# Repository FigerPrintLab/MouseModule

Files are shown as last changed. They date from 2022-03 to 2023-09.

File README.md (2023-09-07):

# MouseModule [WORK IN PROGRESS]

This is an eurorack module that processes mouse events through the [Raspberry Pi](https://www.raspberrypi.org/) and generates some analog signals. It offers also recording and playback capabilities with more complex mice.

## Build instructions 

This is a pretty simple module to build and try if you have a Raspberry Pi.

### Hardware

Inside the repository (in the KiCad folder) you'll find the schematic (the PCB is still WIP) that you can use to build a very simple prototype on a breadboard. All you need are some passive components, a general purpose opamp and a comparator (used as level translator from 3.3V to 5V).  
GPIO 4 can be tied to an LED to get visual feedback when you're recording. Same for GPIO 17 which signals that you're playing back the recorded events.

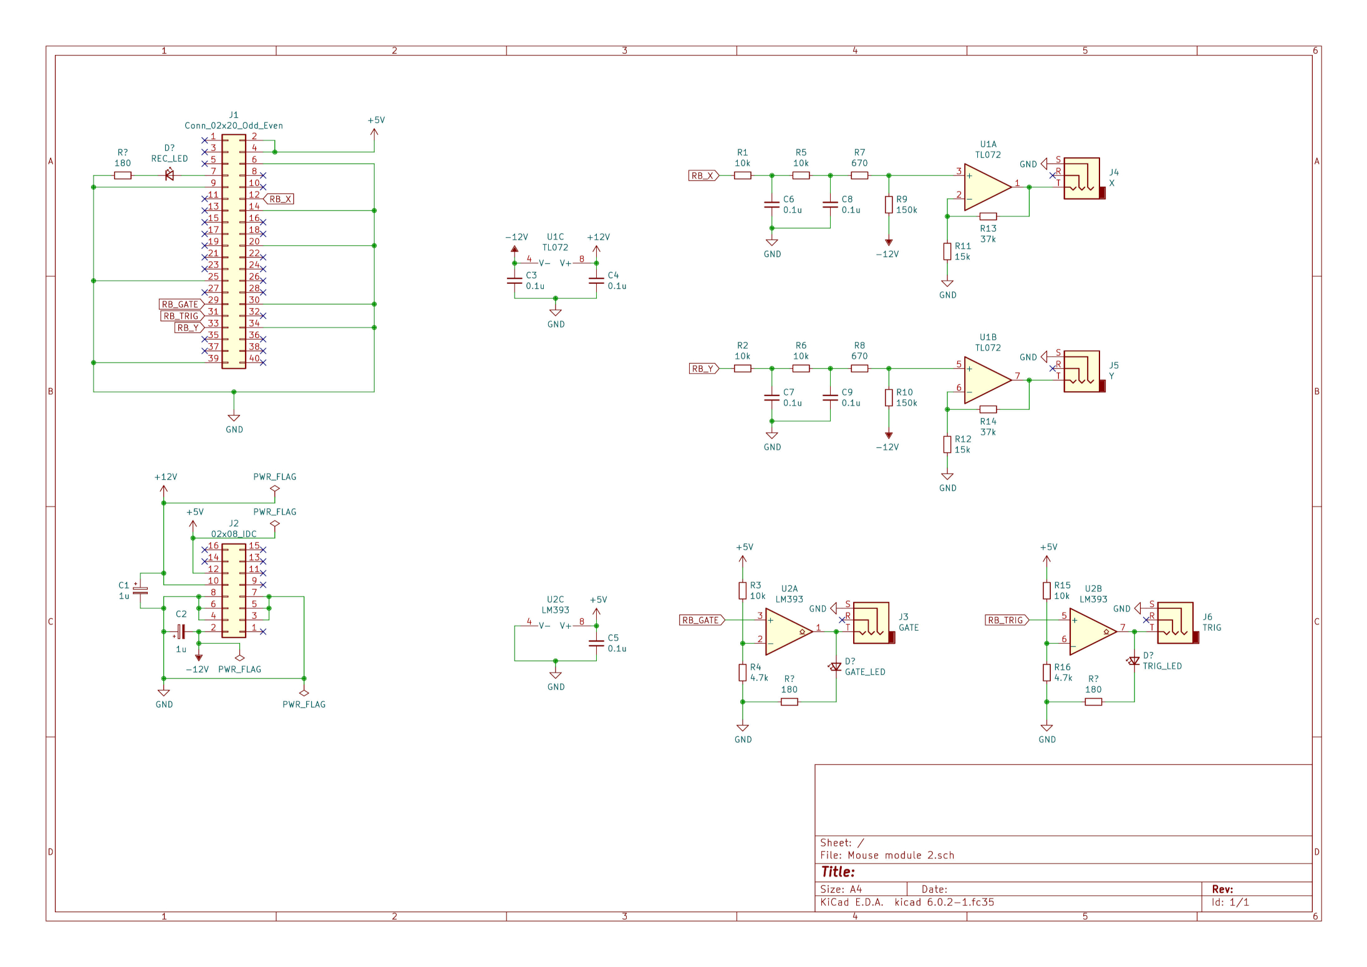
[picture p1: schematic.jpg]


### Software

The program is written in C and it captures all the relevant mouse events in order to generate the appropriate hardware signals on specific GPIOs (listed below). The software should be run on the minimal version of the Pi OS (Raspberry Pi OS Lite) because of the lack of a graphical server which could behave weirdly with the mouse events. In order to compile it you need to install the [`pigpio` library](https://abyz.me.uk/rpi/pigpio/) which requires privileged permissions to run.

```sh
# clone the repository
git clone https://github.com/FingerprintLab/MouseModule.git
cd MouseModule

# install the dependency
sudo apt update && sudo apt upgrade -y
sudo apt install -y pigpio

# compile
cd Software
make

# run
sudo ./main
```

## Features

These are the main features of the module:

- Mouse position -> 2 analog signal for each coordinate
- Left button -> Trigger
- Right button -> Gate
- Middle button -> Change mode (attenuation or offset)
- Wheel -> Increase/decrease attenuation or offset (based on current mode)
- Extra button -> Start/stop the recording
- Side button -> Erase the recording

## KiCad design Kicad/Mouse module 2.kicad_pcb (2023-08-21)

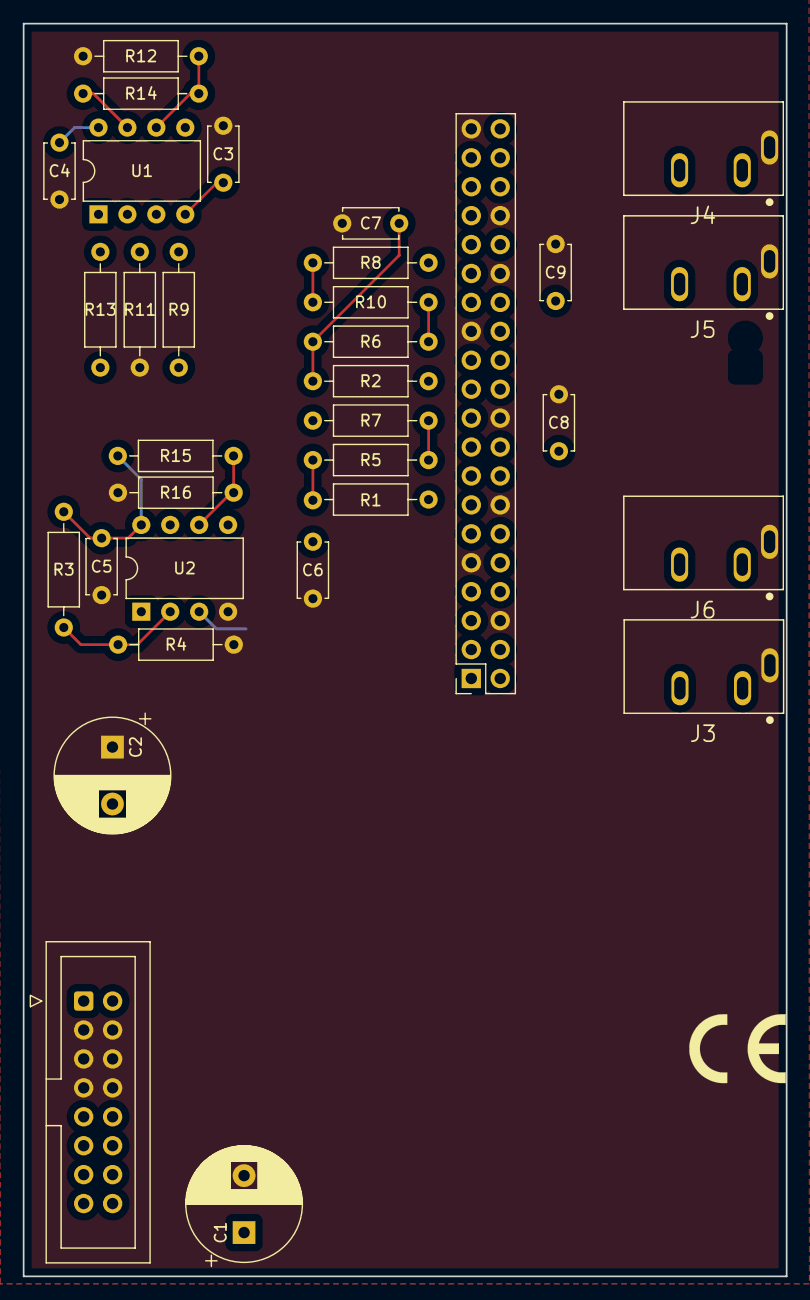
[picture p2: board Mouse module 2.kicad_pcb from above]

Board: 2 copper layers, 67.0 x 110.0 mm, 33 parts (0 on the bottom side), 22 nets.

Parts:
C1, C2: 1uF; CP_Radial_D10.0mm_P5.00mm
C3, C4, C5, C6, C7, C8, C9: 0.1uF; C_Disc_D4.7mm_W2.5mm_P5.00mm
J1: Conn_02x20_Odd_Even; PinSocket_2x20_P2.54mm_Vertical
J2: 02x08_IDC; IDC-Header_2x08_P2.54mm_Vertical
J3: GATE; CUI_SJ1-3533
J4: X; CUI_SJ1-3533
J5: Y; CUI_SJ1-3533
J6: TRIG; CUI_SJ1-3533
R1, R2, R3, R5, R6, R15: 10k; R_Axial_DIN0207_L6.3mm_D2.5mm_P10.16mm_Horizontal
R4, R16: 4.7k; R_Axial_DIN0207_L6.3mm_D2.5mm_P10.16mm_Horizontal
R7, R8: 670; R_Axial_DIN0207_L6.3mm_D2.5mm_P10.16mm_Horizontal
R9, R10: 150k; R_Axial_DIN0207_L6.3mm_D2.5mm_P10.16mm_Horizontal
R11, R12: 15k; R_Axial_DIN0207_L6.3mm_D2.5mm_P10.16mm_Horizontal
R13, R14: 37k; R_Axial_DIN0207_L6.3mm_D2.5mm_P10.16mm_Horizontal
U1: TL072; DIP-8_W7.62mm
U2: LM393; DIP-8_W7.62mm

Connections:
+5V: C5.2, J1.2, J1.4, J2.12, R3.2, R15.2, U2.8
+12V: C1.1, C4.2, J2.10, U1.8
-12V: C2.2, C3.2, J2.2, R9.1, R10.1, U1.4
GND: C1.2, C2.1, C3.1, C4.1, C5.1, C6.1, C7.1, C8.1, C9.1, J1.6, J1.9, J1.14, J1.20, J1.25, J1.30, J1.34, J1.39, J2.3, J2.4, J2.5, J2.6, J2.7, J2.8, J3.S, J4.S, J5.S, J6.S, R4.1, R11.1, R12.1, R16.1, U2.4
unnamed: C6.2, R1.1, R5.2
unnamed: C7.2, R2.1, R6.2
unnamed: C8.2, R5.1, R7.2
unnamed: C9.2, R6.1, R8.2
unnamed: J3.T, U2.1
unnamed: J4.T, R13.1, U1.1
unnamed: J5.T, R14.1, U1.7
unnamed: J6.T, U2.7
unnamed: R3.1, R4.2, U2.2
unnamed: R7.1, R9.2, U1.3
unnamed: R8.1, R10.2, U1.5
unnamed: R11.2, R13.2, U1.2
unnamed: R12.2, R14.2, U1.6
unnamed: R15.1, R16.2, U2.6
RB_GATE: J1.29, U2.3
RB_TRIG: J1.31, U2.5
RB_X: J1.12, R1.2
RB_Y: J1.33, R2.2

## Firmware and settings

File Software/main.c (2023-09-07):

/*
 * This program read some significant mouse events and use
 * them to generate analog signals through the Raspberry PI
 * GPIOs.
 *
 * TODO:
 *  - Handle interrupt signal
 *  - Pass argument as pointer (more efficient than copying the whole struct)
 *  - Should we implement a mutex for the thread variables which are handles also in erase()?
 */

#include <stdio.h>
#include <stdlib.h>
#include <string.h>
#include <pigpio.h>
#include "event.h"

int main(int argc, char** argv)
{
    FILE *devices, *mouse;
    struct input_event systemEvent;
    struct str_event myEvent;

    /* Open the devices file */
    devices = fopen("/proc/bus/input/devices", "r");
    if (devices == NULL) {
        printf("ERROR: Unable to read /proc/bus/input/devices\n");
    }

    /* Get the file path corresponding to the mouse */
    char filePath[18] = "/dev/input/";
    char name[10];
    if (getFileName(devices, name))
        strcat(filePath, name);
    else
        printf("ERROR: Unable to find the mouse file\n");

    /* Open the mouse file */
    mouse = fopen(filePath, "r");
    if(mouse == NULL) {
        printf("ERROR: Unable to read %s\n", filePath);
        return EXIT_FAILURE;
    } else {
        printf("OPENINIG %s\n", filePath);
    }

    /* Initialize the gpios */
    if (gpioInitialise() < 0) return EXIT_FAILURE;
    gpioHardwarePWM(PWM_0, 0, 0);
    gpioHardwarePWM(PWM_1, 0, 0);
    if (gpioSetMode(GATE, PI_OUTPUT) != 0) return EXIT_FAILURE;
    if (gpioSetMode(TRIG, PI_OUTPUT) != 0) return EXIT_FAILURE;
    if (gpioSetMode(REC,  PI_OUTPUT) != 0) return EXIT_FAILURE;
    if (gpioSetMode(PB,   PI_OUTPUT) != 0) return EXIT_FAILURE;

    /* Event polling loop */
    // unsigned long i = 0;
    while(1) {
        /* Read from the mouse file */
        size_t bytes = fread(&systemEvent, sizeof(struct input_event), 1, mouse);

        /* If we managed to read some bytes, print the relative events */
        if (bytes > 0) {
            // printRaw(i, &systemEvent);
            setStrEvent(&systemEvent, &myEvent);
            // printHuman(i, &myEvent);
            // printFunctional(&myEvent, &rec, &mode);
            handle(&systemEvent);
            /* Uncomment to get the incremental number of events */
            // i++;
        }
    }
    gpioTerminate();
    return EXIT_SUCCESS;
}

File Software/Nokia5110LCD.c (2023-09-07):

// Nokia5110LCD.c

#include "Nokia5110LCD.h"
#include <pigpio.h>
#include <stdlib.h>
#include <string.h>
#include <stdio.h>

/** the memory buffer for the LCD */
char pcd8544_buffer[LCDWIDTH * LCDHEIGHT / 8] = {
    0x00, 0x00, 0x00, 0x00, 0x00, 0x00, 0x00, 0x00, 0x00, 0x00, 0x00, 0x00,
    0x00, 0x00, 0x00, 0x00, 0x00, 0x00, 0x00, 0x00, 0x00, 0x00, 0x00, 0x00,
    0x00, 0x00, 0x00, 0x00, 0x00, 0x00, 0x00, 0x00, 0x00, 0x00, 0x00, 0x00,
    0x00, 0x00, 0xC0, 0xE0, 0xF0, 0xF8, 0xFC, 0xFC, 0xFE, 0xFF, 0xFC, 0xE0,
    0x00, 0x00, 0x00, 0x00, 0x00, 0x00, 0x00, 0x00, 0x00, 0x00, 0x00, 0x00,
    0x00, 0x00, 0x00, 0x00, 0x00, 0x00, 0x00, 0x00, 0x00, 0x00, 0x00, 0x00,
    0x00, 0x00, 0x00, 0x00, 0x00, 0x00, 0x00, 0x00, 0x00, 0x00, 0x00, 0x00,
    0x00, 0x00, 0x00, 0x00, 0x00, 0x00, 0x00, 0x00, 0x00, 0x00, 0x00, 0x00,
    0x00, 0x00, 0x00, 0x00, 0x00, 0xF8, 0xF8, 0xF8, 0xF8, 0xF8, 0xF8, 0xF8,
    0xF8, 0xF8, 0xF8, 0xF8, 0xF8, 0xF0, 0xF0, 0xE0, 0xE0, 0xC0, 0x80, 0xC0,
    0xFC, 0xFF, 0xFF, 0xFF, 0xFF, 0x7F, 0x3F, 0x7F, 0xFF, 0xFF, 0xFF, 0xFF,
    0xFF, 0x00, 0x00, 0x00, 0x00, 0x00, 0x00, 0x00, 0x00, 0x00, 0x00, 0x00,
    0x00, 0x00, 0x00, 0x00, 0x00, 0x00, 0x00, 0x00, 0x00, 0x00, 0x00, 0x00,
    0x00, 0x00, 0x00, 0x00, 0x00, 0x00, 0x00, 0x00, 0x00, 0x00, 0x00, 0x00,
    0x00, 0x00, 0x00, 0x00, 0x00, 0x00, 0x00, 0x00, 0x00, 0x00, 0x00, 0x00,
    0x00, 0x00, 0x00, 0x00, 0x00, 0x00, 0x0F, 0x1F, 0x3F, 0x7F, 0xFF, 0xFF,
    0xFF, 0xFF, 0xFF, 0xFF, 0xFF, 0xFF, 0xE7, 0xC7, 0xC7, 0x87, 0x8F, 0x9F,
    0x9F, 0xFF, 0xFF, 0xFF, 0xC1, 0xC0, 0xE0, 0xFC, 0xFF, 0xFF, 0xFF, 0xFF,
    0xFF, 0xFC, 0xFC, 0xFC, 0xFC, 0xFE, 0xFE, 0xFE, 0xFC, 0xFC, 0xF8, 0xF8,
    0xF0, 0xE0, 0xC0, 0xC0, 0x00, 0x00, 0x00, 0x00, 0x00, 0x00, 0x00, 0x00,
    0x00, 0x00, 0x00, 0x00, 0x00, 0x00, 0x00, 0x00, 0x00, 0x00, 0x00, 0x00,
    0x00, 0x00, 0x00, 0x00, 0x00, 0x00, 0x00, 0x00, 0x00, 0x00, 0x00, 0x00,
    0x00, 0x00, 0x00, 0x00, 0x00, 0x00, 0x00, 0x00, 0x00, 0x80, 0xC0, 0xE0,
    0xF1, 0xFB, 0xFF, 0xFF, 0xFF, 0xFF, 0xFF, 0x7F, 0x1F, 0x0F, 0x0F, 0x87,
    0xE7, 0xFF, 0xFF, 0xFF, 0x1F, 0x1F, 0x3F, 0xF9, 0xF8, 0xF8, 0xF8, 0xF8,
    0xF8, 0xF8, 0xFD, 0xFF, 0xFF, 0xFF, 0xFF, 0xFF, 0xFF, 0xFF, 0xFF, 0xFF,
    0x7F, 0x3F, 0x0F, 0x07, 0x01, 0x00, 0x00, 0x00, 0x00, 0x00, 0x00, 0x00,
    0x00, 0x00, 0x00, 0x00, 0x00, 0x00, 0x00, 0x00, 0x00, 0x00, 0x00, 0x00,
    0x00, 0x00, 0x00, 0x00, 0x00, 0x00, 0x00, 0x00, 0x00, 0x00, 0x00, 0x00,
    0x00, 0x00, 0x00, 0x00, 0x00, 0x00, 0x00, 0xF0, 0xFE, 0xFF, 0xFF, 0xFF,
    0xFF, 0xFF, 0xFF, 0xFF, 0xFF, 0xFF, 0xFF, 0xFE, 0x7E, 0x3F, 0x3F, 0x0F,
    0x1F, 0xFF, 0xFF, 0xFF, 0xFC, 0xF0, 0xE0, 0xF1, 0xFF, 0xFF, 0xFF, 0xFF,
    0xFF, 0xFC, 0xF0, 0x01, 0x01, 0x01, 0x01, 0x01, 0x01, 0x01, 0x01, 0x00,
    0x00, 0x00, 0x00, 0x00, 0x00, 0x00, 0x00, 0x00, 0x00, 0x00, 0x00, 0x00,
    0x00, 0x00, 0x00, 0x00, 0x00, 0x00, 0x00, 0x00, 0x00, 0x00, 0x00, 0x00,
    0x00, 0x00, 0x00, 0x00, 0x00, 0x00, 0x00, 0x00, 0x00, 0x00, 0x00, 0x00,
    0x00, 0x00, 0x00, 0x00, 0x00, 0x00, 0x00, 0x03, 0x03, 0x03, 0x03, 0x03,
    0x03, 0x03, 0x03, 0x01, 0x01, 0x01, 0x01, 0x00, 0x00, 0x00, 0x00, 0x00,
    0x00, 0x00, 0x03, 0x0F, 0x1F, 0x3F, 0x7F, 0x7F, 0xFF, 0xFF, 0xFF, 0xFF,
    0x7F, 0x7F, 0x1F, 0x03, 0x00, 0x00, 0x00, 0x00, 0x00, 0x00, 0x00, 0x00,
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
};

int begin(DisplayInfo* d)
{
    int spiHandle = spiOpen(SPI_CHANNEL, SPI_CLK, 0);
    if (spiHandle < 0) return 1;
    d->_spiHandle = spiHandle;

    // Set common pin outputs.
    d->_rstpin = RST;
    d->_dcpin = DC;
    if (gpioSetMode(d->_rstpin, PI_OUTPUT) < 0) return 1;
    if (gpioSetPullUpDown(d->_rstpin, PI_PUD_UP) < 0) return 1;
    if (gpioSetMode(d->_dcpin, PI_OUTPUT) < 0) return 1;

    d->_bias = BIAS;
    d->_contrast = CONTRAST;
    d->_reinit_interval = 0;
    d->_display_count = 0;

    initDisplay(d);

    // initial display line
    // set page address
    // set column address
    // write display data

    // set up a bounding box for screen updates

    // updateBoundingBox(d, 0, 0, LCDWIDTH - 1, LCDHEIGHT - 1);
    // Push out pcd8544_buffer to the Display (will show the AFI logo)
    // display(d);

    return 0;
}

void initDisplay(DisplayInfo* d)
{
    // toggle RST low to reset
    if (d->_rstpin >= 0) {
        gpioWrite(d->_rstpin, LOW);
        gpioSleep(PI_TIME_RELATIVE, 0, 1000); // 1 ns minimum
        gpioWrite(d->_rstpin, HIGH);
    }

    setBias(d, BIAS);
    setContrast(d, CONTRAST);

    // normal mode
    command(d, PCD8544_FUNCTIONSET);

    // Set display to Normal
    command(d, PCD8544_DISPLAYCONTROL | PCD8544_DISPLAYNORMAL);
}

void setBias(DisplayInfo* d, char val)
{
    if (val > 0x07) {
        val = 0x07;
    }
    d->_bias = val;
    command(d, PCD8544_FUNCTIONSET | PCD8544_EXTENDEDINSTRUCTION);
    command(d, PCD8544_SETBIAS | val);
    command(d, PCD8544_FUNCTIONSET);
}

void setContrast(DisplayInfo* d, char val)
{
    if (val > 0x7f) {
        val = 0x7f;
    }
    d->_contrast = val;
    command(d, PCD8544_FUNCTIONSET | PCD8544_EXTENDEDINSTRUCTION);
    command(d, PCD8544_SETVOP | val);
    command(d, PCD8544_FUNCTIONSET);
}

void setReinitInterval(DisplayInfo* d, char val)
{
    d->_reinit_interval = val;
}

void command(DisplayInfo* d, char c)
{
    gpioWrite(d->_dcpin, LOW);
    spiWrite(d->_spiHandle, &c, 1);
}

void data(DisplayInfo* d, char c)
{
    gpioWrite(d->_dcpin, HIGH);
    spiWrite(d->_spiHandle, &c, 1);
}

void updateBoundingBox(DisplayInfo* d,
                       char xmin, char ymin,
                       char xmax, char ymax)
{
    d->xUpdateMin = min(d->xUpdateMin, xmin);
    d->xUpdateMax = max(d->xUpdateMax, xmax);
    d->yUpdateMin = min(d->yUpdateMin, ymin);
    d->yUpdateMax = max(d->yUpdateMax, ymax);
}

char min(const char a, const char b)
{
    return (a < b ? a : b);
}

char max(const char a, const char b)
{
    return (a > b ? a : b);
}

void drawPixel(int16_t x, int16_t y, uint16_t color)
{
    setPixel(x, y, color, pcd8544_buffer);
}

void setAddress(DisplayInfo* d, bool x, char address)
{
    if (x) {
        if (address < 0 || address > 83) return;
        gpioWrite(d->_dcpin, LOW);
        char c = PCD8544_SETXADDR | address;
        spiWrite(d->_spiHandle, &c, 1);
    } else { //y
        if (address < 0 || address > 5) return;
        gpioWrite(d->_dcpin, LOW);
        char c = PCD8544_SETYADDR | address;
        spiWrite(d->_spiHandle, &c, 1);
    }
}

void setBothAddresses(DisplayInfo* d, char x, char y)
{
    if (x < 0 || x > 83 || y < 0 || y > 5) return;
    gpioWrite(d->_dcpin, LOW);
    char c[2] = { PCD8544_SETYADDR | y, PCD8544_SETXADDR | x };
    spiWrite(d->_spiHandle, c, 2);
    // c = PCD8544_SETXADDR | x;
    // spiWrite(d->_spiHandle, &c, 1);

}
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

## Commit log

2021-08-05 added module for raspberry's functions
2021-08-05 general cleanup & dual TL072
    [Mouse module 2-B_Cu.gbr, Mouse module 2-B_Mask.gbr, Mouse module 2-B_SilkS.gbr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]
2021-11-29 work on PCB & added some LEDs
    [Mouse module 2.kicad_pcb, Mouse module 2.sch]
2021-11-29 software control of record and playback LEDs
2022-03-13 Added pwm experiment
2022-03-14 added pwm module & cleanup
2022-03-16 cleanup & pwm read & gpio
2022-03-16 succesfull pwm test
2022-03-16 removed pwm & gpio files in favor of pigpio lib
2022-03-19 hw signals achieved & removed GATE bug on some mice
    [event.c, event.h, main.c]
2022-03-20 achieved movement constrain on attenuation/offset & removed playback timing bug
    [event.c, event.h, main.c]
2022-03-20 updated Kicad files
    [Mouse module 2-B_Cu.gbr, Mouse module 2-B_Mask.gbr, Mouse module 2-B_SilkS.gbr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]
2023-08-21 update KiCad version
    [Mouse module 2.kicad_pcb, Mouse module 2.kicad_sch]
